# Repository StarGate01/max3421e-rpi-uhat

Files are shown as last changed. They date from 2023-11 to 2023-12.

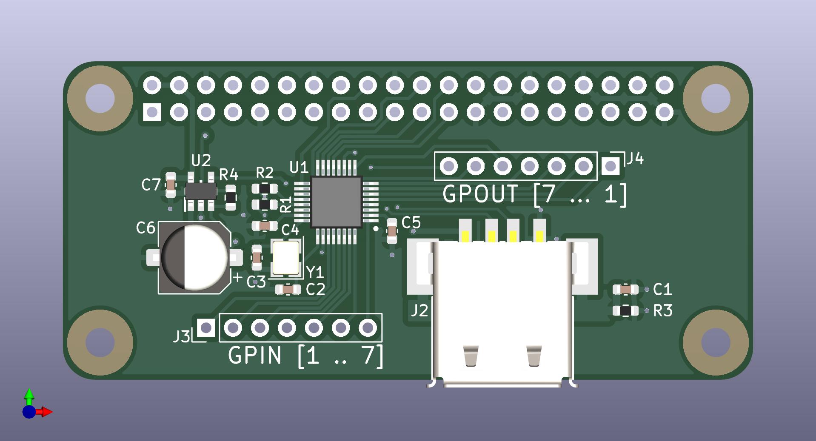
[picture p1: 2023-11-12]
export/drawing/max3421e-rpi-uhat_top.jpg

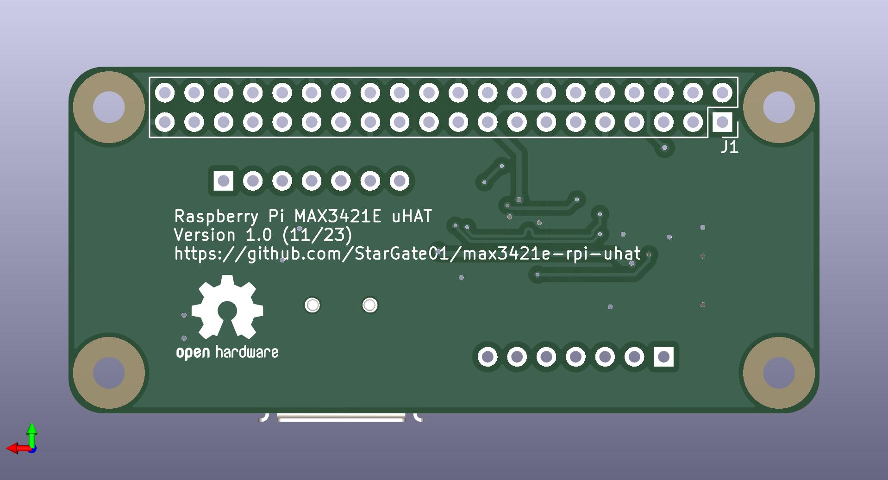
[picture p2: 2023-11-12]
export/drawing/max3421e-rpi-uhat_bottom.jpg

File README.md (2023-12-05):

# Raspberry Pi MAX3421E uHAT Hardware

A uHAT for the Raspberry Pi (Zero), which adds a second USB 2.0 controller over SPI, using the MAX3421E chip.

Also read my blog post for this project: https://chrz.de/2023/12/05/fido2-hardware-part-2-usb-host-circuit-boards/

KiCAD version 7 is used to edit the files. Inspired by the Mini USB Host Shield 2.0 (https://laborjag.com/venta/arduino/mini-usb-host-shield-2-0/).

## Setup with Raspberry Pi OS

See § "Compiling the MAX3421-HCD Kernel Driver" and § "Automatic Driver Loading and Device Tree Configuration" of my blog post at https://chrz.de/2023/11/07/fido2-protocol-translation-hardware/

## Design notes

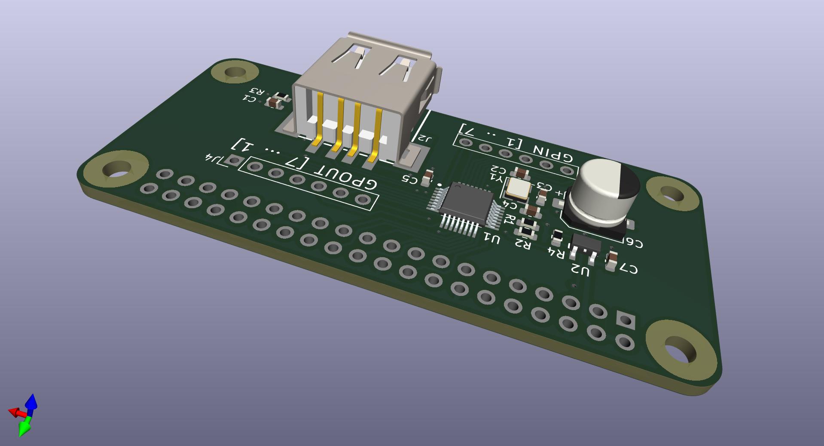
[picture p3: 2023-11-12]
export/drawing/max3421e-rpi-uhat_top_persp.jpg

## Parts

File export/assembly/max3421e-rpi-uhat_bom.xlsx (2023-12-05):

 |  |  | max3421e-rpi-uhat BOM
Item # | *Designator | *Qty | Manufacturer | *Mfg Part # | Description / Value | *Package/Footprint | Type | Your Instructions / Notes
1 | Y1 | 1 | JWT | CF4012M00012 | CRYSTAL 12MHZ MAX.1000 PPM, GND PIN 2+4 | 3225 4PIN 3.2x2.5MM | SMD
2 | C7,C5,C4 | 3 | ANY | TBD | CAP CER 0.1UF MIN.10V X7R | 0603 | SMD
3 | C1 | 1 | ANY | TBD | CAP CER 4.7NF MIN.10V X7R | 0603 | SMD
4 | J2 | 1 | JING EXTENSION OF THE ELECTRONIC CO. | 904-131A2032S10100 | USB 2.0 FEMALE TYPE-A CONNECTOR | 904-131A2032S10100 | SMD
5 | C3,C2 | 2 | ANY | TBD | CAP CER 18PF MIN.10V X7R | 0603 | SMD
6 | R2,R1 | 2 | ANY | TBD | RES 33 OHM 1/8W 1% | 0603 | SMD
7 | U2 | 1 | TEXAS INSTRUMENTS | TPS2065CDBVR | 1A POWER DISTRIBUTION SWITCH | SOT-23-5 | SMD
8 | R3 | 1 | ANY | TBD | RES 1M OHM 1/8W 5% | 0603 | SMD
9 | U1 | 1 | ANALOG DEVICES INC./MAXIM INTEGRATED | MAX3421EEHJ+T | USB 2.0 SPI HOST CONTROLLER | TQFP-32 | SMD
10 | C6 | 1 | ANY | TBD | CAP POL ELECTROLYTIC 150UF MIN.10V 20% | D6.3xL5.4MM | SMD
11 | R4 | 1 | ANY | TBD | RES 10K OHM 1/8W 5% | 0603 | SMD

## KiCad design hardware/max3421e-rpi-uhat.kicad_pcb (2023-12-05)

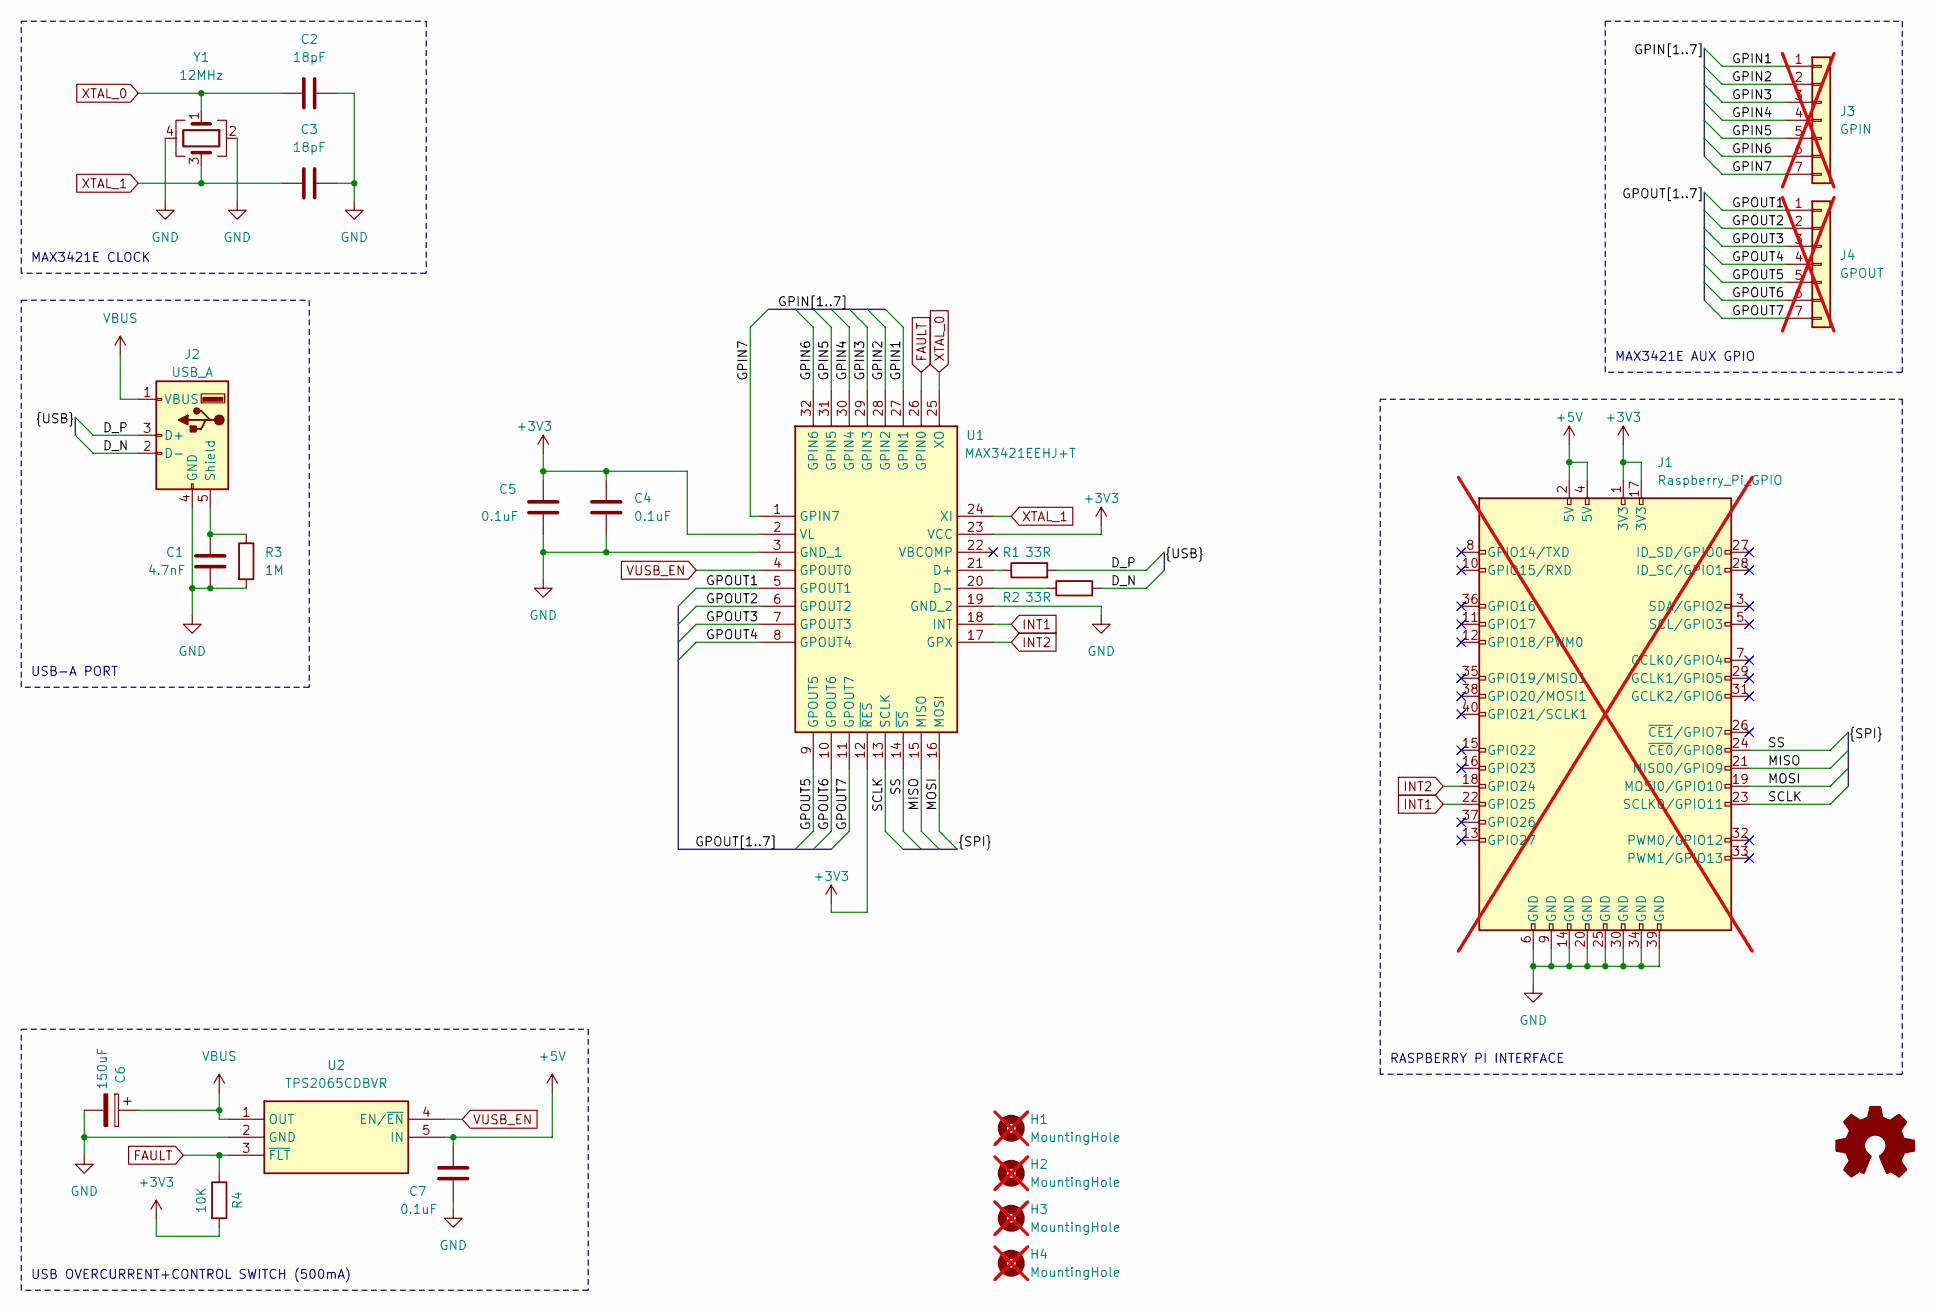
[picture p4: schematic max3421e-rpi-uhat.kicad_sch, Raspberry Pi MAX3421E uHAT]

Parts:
C1: 4.7nF; C_0603_1608Metric; MPN TBD
C2, C3: 18pF; C_0603_1608Metric; MPN TBD
C4, C5: 0.1uF; C_0603_1608Metric; MPN TBD
C6: 150uF; CP_Elec_6.3x5.4; MPN TBD
C7: 0.1uF; C_0603_1608Metric
H1, H2, H3, H4: MountingHole; MountingHole_2.75mm_6.2mm; MPN N/A; not fitted
J1: Raspberry_Pi_GPIO; PinSocket_2x20_P2.54mm_Vertical; MPN N/A; not fitted
J2: USB_A; USB-A-SMD_FUS270-FSBW5K; MPN 904-131A2032S10100
J3: GPIN; PinHeader_1x07_P2.54mm_Vertical; MPN N/A; not fitted
J4: GPOUT; PinHeader_1x07_P2.54mm_Vertical; MPN N/A; not fitted
R1, R2: 33R; R_0603_1608Metric; MPN TBD
R3: 1M; R_0603_1608Metric; MPN TBD
R4: 10K; R_0603_1608Metric
U1: MAX3421EEHJ+T; QFP50P700X700X120-32N; MPN MAX3421EEHJ+T
U2: TPS2065CDBVR; SOT95P280X145-5N; MPN TPS2065CDBVR
Y1: 12MHz; Crystal_SMD_3225-4Pin_3.2x2.5mm; MPN TBD

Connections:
+3V3: C4.1, C5.1, J1.1 (3V3), J1.17 (3V3), R4.2, U1.2 (VL), U1.12 (~RES), U1.23 (VCC)
+5V: C7.1, J1.2 (5V), J1.4 (5V), U2.5 (IN)
/D_N: J2.2 (D-), R2.2
/D_P: J2.3 (D+), R1.2
/GPIN1: J3.1, U1.27 (GPIN1)
/GPIN2: J3.2, U1.28 (GPIN2)
/GPIN3: J3.3, U1.29 (GPIN3)
/GPIN4: J3.4, U1.30 (GPIN4)
/GPIN5: J3.5, U1.31 (GPIN5)
/GPIN6: J3.6, U1.32 (GPIN6)
/GPIN7: J3.7, U1.1 (GPIN7)
/GPOUT1: J4.1, U1.5 (GPOUT1)
/GPOUT2: J4.2, U1.6 (GPOUT2)
/GPOUT3: J4.3, U1.7 (GPOUT3)
/GPOUT4: J4.4, U1.8 (GPOUT4)
/GPOUT5: J4.5, U1.9 (GPOUT5)
/GPOUT6: J4.6, U1.10 (GPOUT6)
/GPOUT7: J4.7, U1.11 (GPOUT7)
/MISO: J1.21 (MISO0/GPIO9), U1.15 (MISO)
/MOSI: J1.19 (MOSI0/GPIO10), U1.16 (MOSI)
/SCLK: J1.23 (SCLK0/GPIO11), U1.13 (SCLK)
/SS: J1.24 (~CE0/GPIO8), U1.14 (~SS)
FAULT: R4.1, U1.26 (GPIN0), U2.3 (~FLT)
GND: C1.1, C2.1, C3.1, C4.2, C5.2, C6.2, C7.2, J1.6 (GND), J1.9 (GND), J1.14 (GND), J1.20 (GND), J1.25 (GND), J1.30 (GND), J1.34 (GND), J1.39 (GND), J2.4 (GND), R3.2, U1.3 (GND_1), U1.19 (GND_2), U2.2 (GND), Y1.2, Y1.4
INT1: J1.22 (GPIO25), U1.18 (INT)
INT2: J1.18 (GPIO24), U1.17 (GPX)
unnamed: C1.2, J2.5 (Shield), R3.1
unnamed: R1.1, U1.21 (D+)
unnamed: R2.1, U1.20 (D-)
VBUS: C6.1, J2.1 (VBUS), U2.1 (OUT)
VUSB_EN: U1.4 (GPOUT0), U2.4 (EN/~EN)
XTAL_0: C2.2, U1.25 (XO), Y1.1
XTAL_1: C3.2, U1.24 (XI), Y1.3

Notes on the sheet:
RASPBERRY PI INTERFACE
MAX3421E AUX GPIO
MAX3421E CLOCK
USB-A PORT
USB OVERCURRENT+CONTROL SWITCH (500mA)

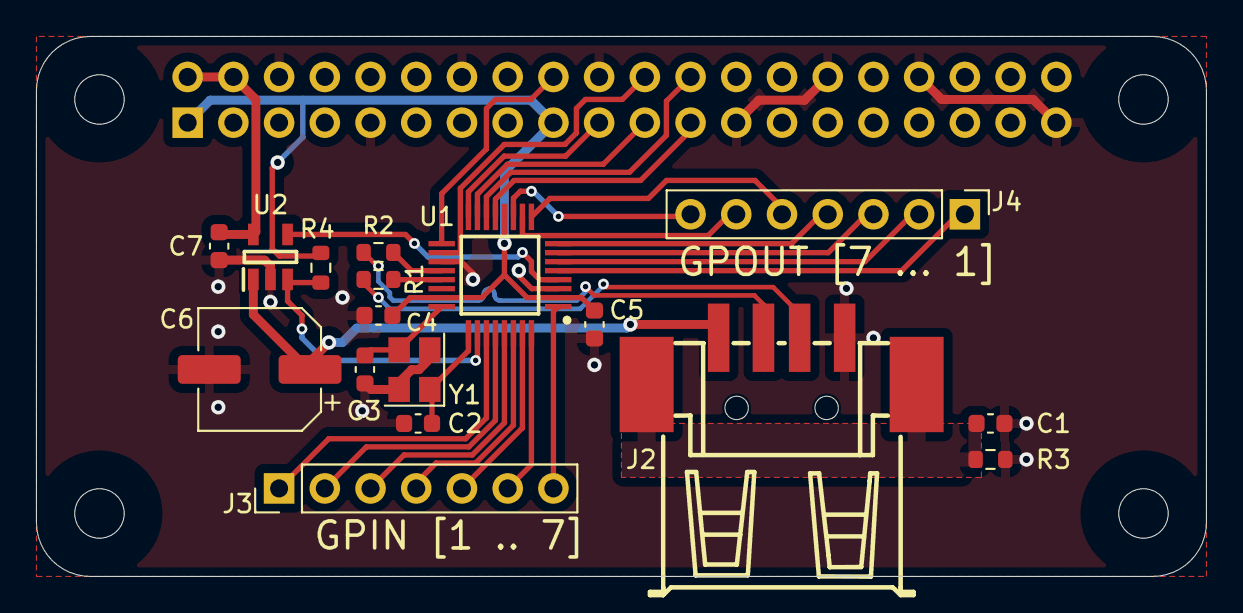
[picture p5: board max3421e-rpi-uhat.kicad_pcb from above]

Board: 2 copper layers, 65.0 x 30.0 mm, 22 parts (1 on the bottom side), 33 nets.

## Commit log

2023-11-11 init project and add docs
    [max3421e-rpi-uhat.kicad_pcb, max3421e-rpi-uhat.kicad_sch]
2023-11-11 set up board
    [max3421e-rpi-uhat.kicad_pcb, max3421e-rpi-uhat.kicad_sch]
2023-11-12 Design version 1.0
    [max3421e-rpi-uhat.kicad_pcb, max3421e-rpi-uhat.kicad_sch]
2023-11-12 Export version 1.0
    [max3421e-rpi-uhat-B_Cu.gbl, max3421e-rpi-uhat-B_Mask.gbs, max3421e-rpi-uhat-B_Paste.gbp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]
2023-12-05 fix bom
    [max3421e-rpi-uhat.kicad_pcb, max3421e-rpi-uhat_bom.xlsx]
